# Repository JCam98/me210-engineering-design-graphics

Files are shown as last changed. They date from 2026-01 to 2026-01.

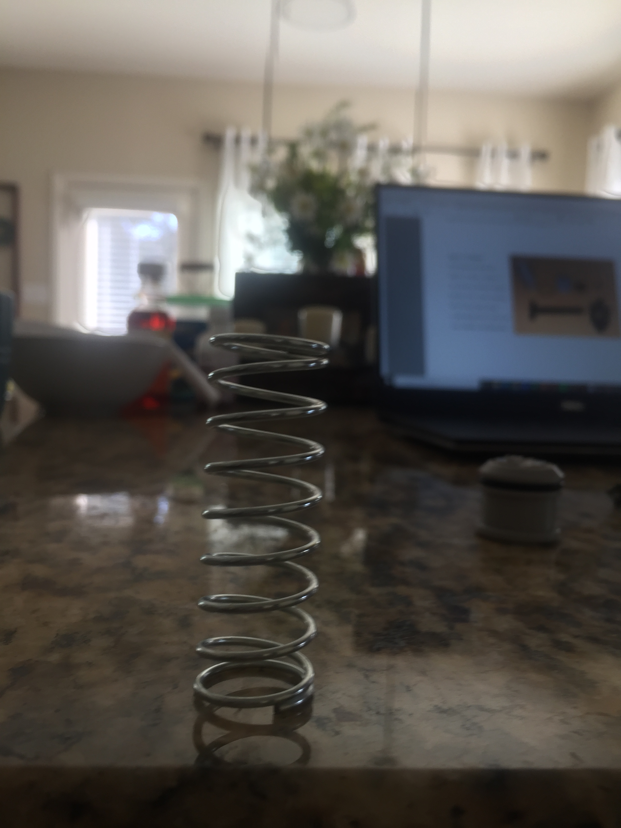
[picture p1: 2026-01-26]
Assignments/Reverse Engineering Project/Design Checks/Design_Check_2/Dissection_Notes/Plunger_Assembly_Spring/IMG-2650.JPG

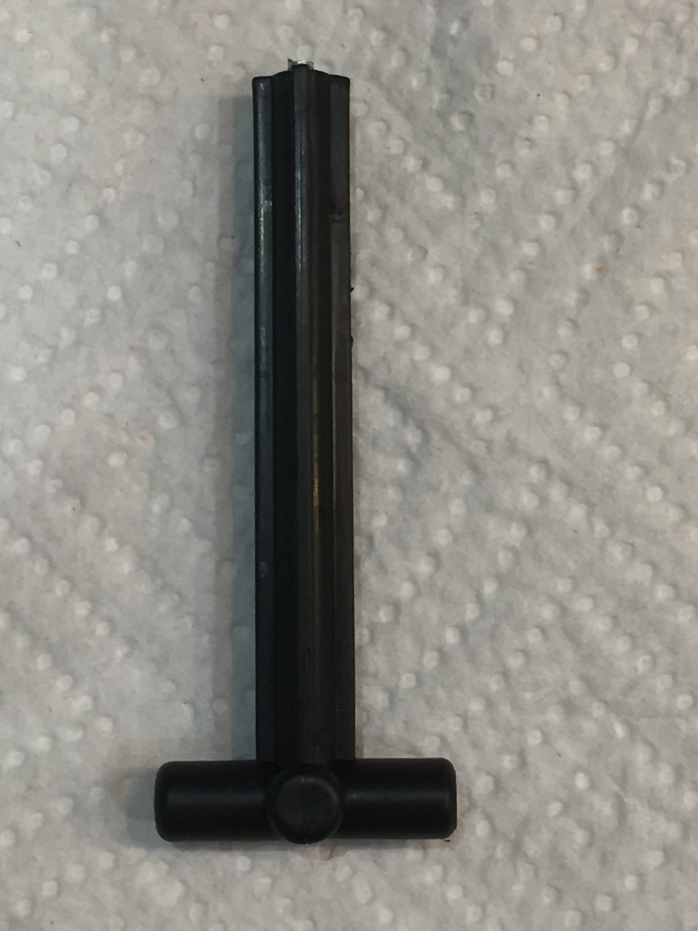
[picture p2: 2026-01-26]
Assignments/Reverse Engineering Project/Design Checks/Design_Check_2/Dissection_Notes/Plunger_Assembly_Shaft/IMG-2728.JPG

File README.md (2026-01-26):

# ME 210 - Engineering Design Graphics

## Description
This is an academic coursework repository containing a reverse engineering project for the course, ME 210: Engineering Design Graphics. This project documents a comprehensive reverse engineering analysis of a Nerf Rebelle toy blaster conducted as part of a mechanical engineering design course. The objective was to disassemble the product, understand its functional subsystems, and recreate the design through detailed engineering documentation and analysis. 

The work includes exploded assembly and sub-assembly sketches, mass properties evaluation, finite element analysis (FEA) of critical components under multiple load cases, and fully dimensioned orthographic drawings. Based on structural and performance insights gained from the analysis, a targeted redesign was proposed to improve component performance while maintaining functionality. Overall, the project demonstrates a structured approach to product teardown, mechanical analysis, and design improvement using industry-standard engineering methods and tools.

## Academic Use Notice
This repository contains completed coursework. Current students should not submit this work as their own.

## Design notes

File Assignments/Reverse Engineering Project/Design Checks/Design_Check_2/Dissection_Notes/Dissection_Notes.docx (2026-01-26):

Dissection Notes

1) To fully dissect the nerf gun, the plunger assembly (consisting of parts 1-8) was first removed from the plastic casing by unscrewing the four stainless steel screws connecting the baseplate to the plastic casing.
2) A flathead tool was then used to remove the rubber o-ring, rubber seal, and steel rivet on the top of the plastic shaft head of the plunger.
3) This, in turn, allowed for three remaining pieces of the plunger assembly, (plastic shaft head, plastic shaft, and plunger assembly spring) to be disassembled.
4) Next, a hacksaw was used to split the plastic casing of the gun into two equal parts, and allowed for the removal of the plastic trigger from the housing assembly.
5) The segment of the plastic casing with the barrel was then disassembled by removing the barrel spring by hand from its two fixed supports, which in turn, allowed for the barrel back panel to be removed. The last remaining part in the housing assembly, the bullet holder is fixed at one end, and free to rotate into and out of the barrel at the other.

Views of the plunger and housing assemblies along with their associated components in the order in which they are disassembled will be provided in detail below.

Full Dissection

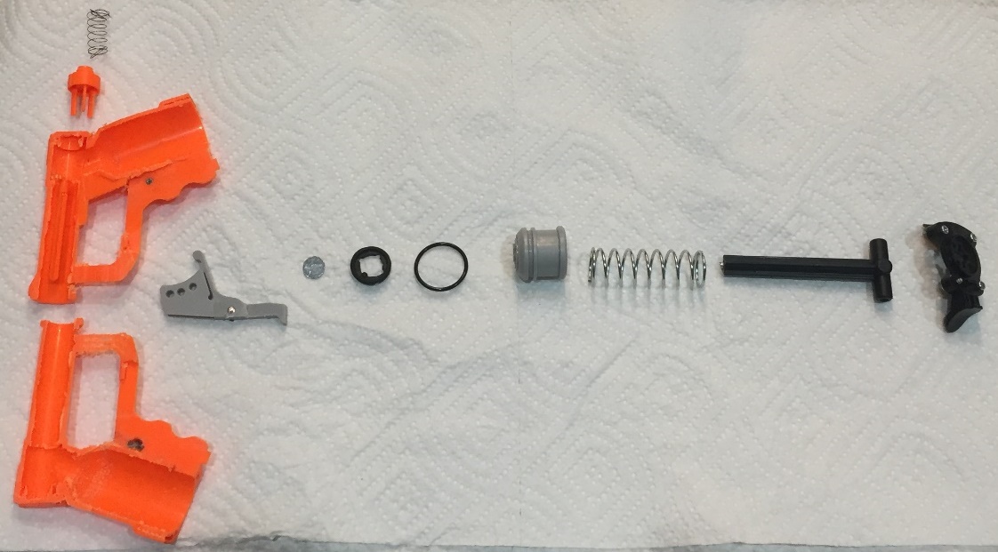
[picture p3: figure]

Figure 1: Full Dissection of the Nerf Gun

Plunger Assembly

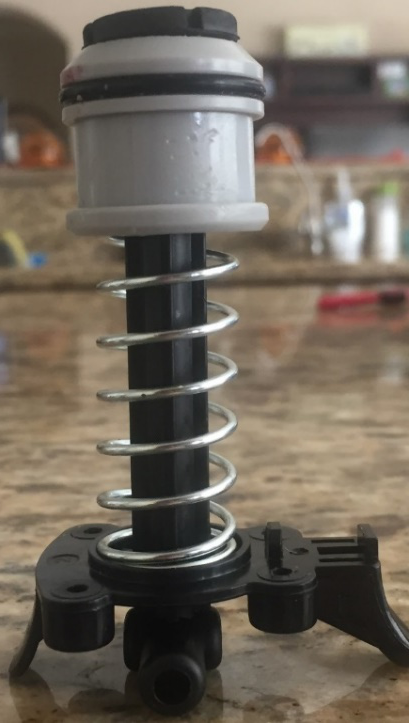
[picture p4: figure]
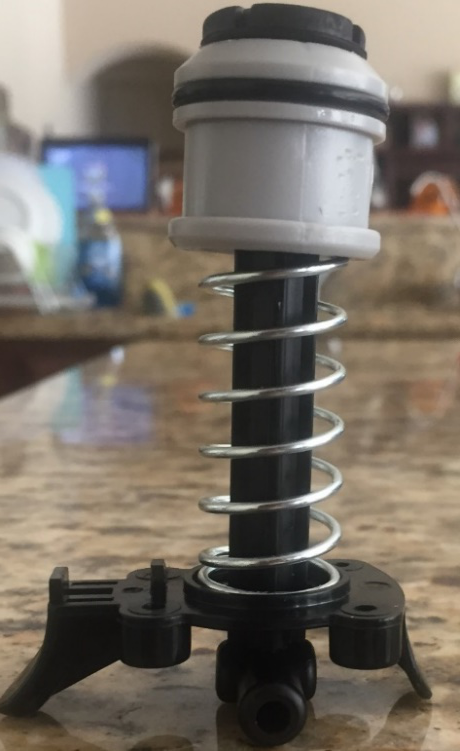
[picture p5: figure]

Figure 5: Plunger Assembly (Right View)

Figure 2: Plunger Assembly (Front View)

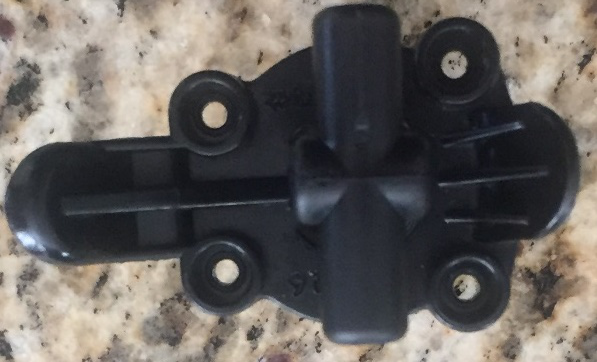
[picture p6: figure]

Figure 7: Plunger Assembly (Bottom View)

Figure 4: Plunger Assembly (Left View)

Figure 3: Plunger Assembly (Back View)

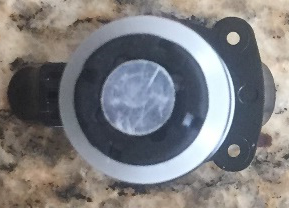
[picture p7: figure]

Figure 6: Plunger Assembly (Top View)

Plunger Dissassembly

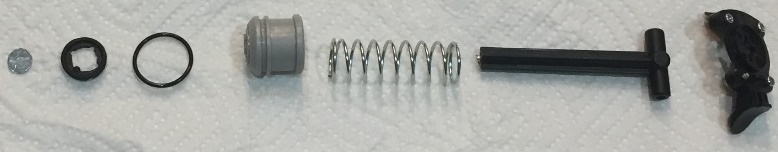
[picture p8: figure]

Figure 8: Disassembly of the Plunger

Baseplate

Figure 11: Plunger Assembly Baseplate (Left View)

Figure 9: Plunger Assembly Baseplate (Front View)

Figure 10: Plunger Assembly Baseplate (Back View)

Figure 12: Plunger Assembly Baseplate (Right View)

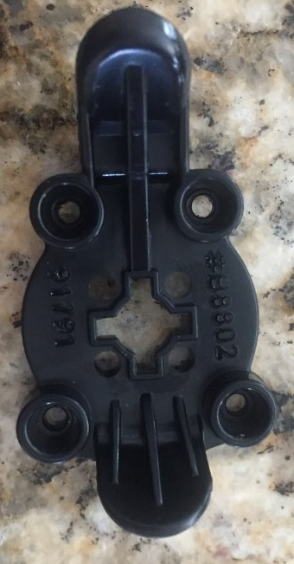
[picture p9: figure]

Figure 14: Plunger Assembly Baseplate (Bottom View)

Figure 13: Plunger Assembly Baseplate (Top View)

Phillips Screws

Figure 15: Phillips Screws

Plunger Assembly Shaft

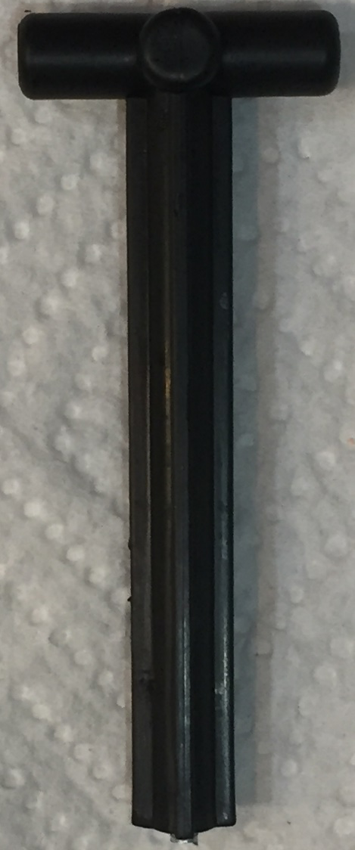
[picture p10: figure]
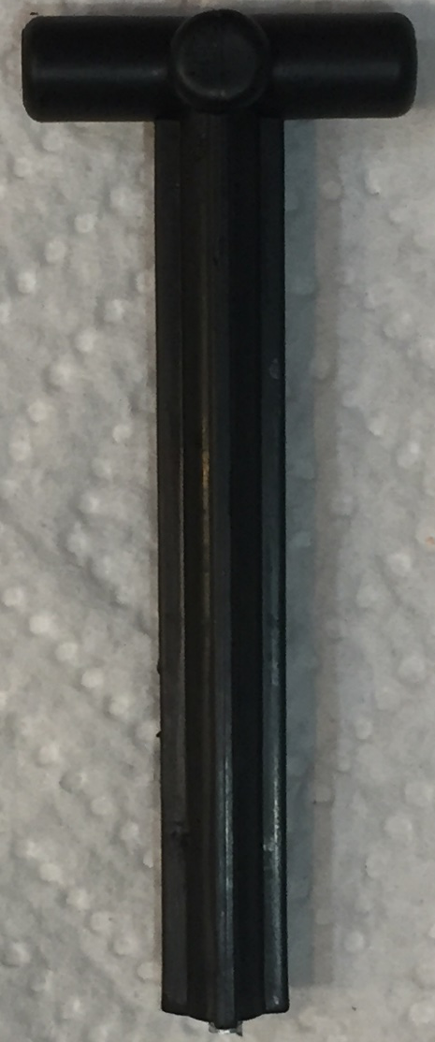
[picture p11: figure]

Figure 16: Plunger Assembly Shaft (Front View)

Figure 19: Plunger Assembly Shaft (Right View)

Figure 18: Plunger Assembly Shaft (Left View)

Figure 17: Plunger Assembly Shaft (Back View)

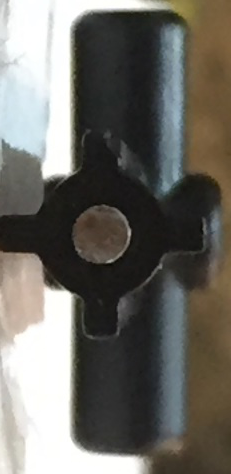
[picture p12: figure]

Figure 21: Plunger Assembly Shaft (Bottom View)

Figure 20: Plunger Assembly Shaft (Top View)

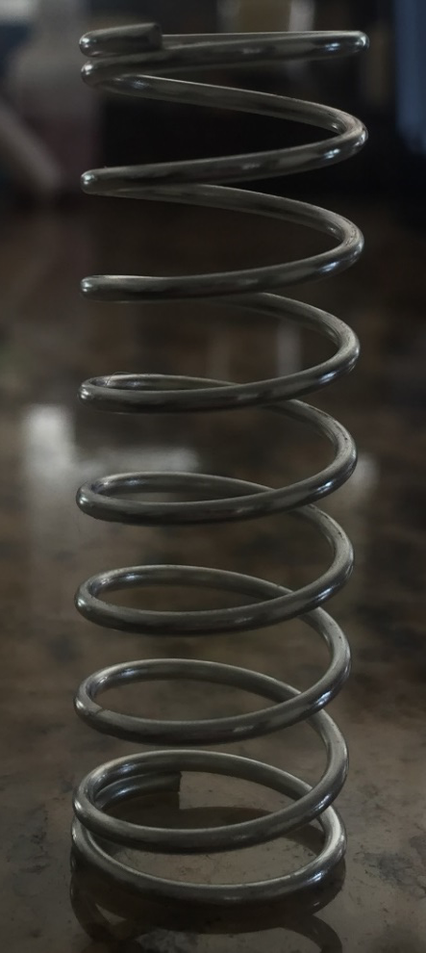
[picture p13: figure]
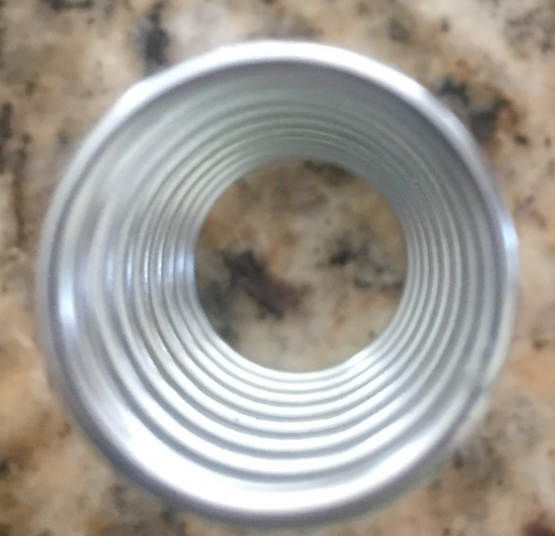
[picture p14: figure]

Plunger Assembly Spring

Figure 22: Plunger Assembly Spring (Side View)

Figure 22: Plunger Assembly Spring (Bottom View)

Figure 22: Plunger Assembly Spring (Top View)

Plunger Assembly Rubber O-Ring

Figure 24: Plunger Assembly Rubber O-Ring (Side View)

Figure 23: Plunger Assembly Rubber O-Ring (Top View)

Plunger Assembly Rubber Seal

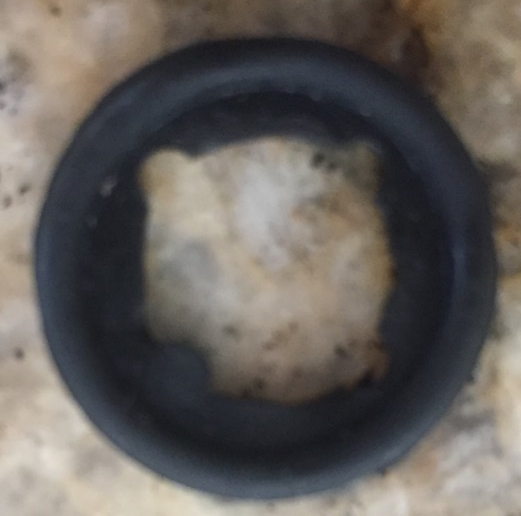
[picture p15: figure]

Figure 25: Plunger Assembly Rubber Seal (Top View)

Figure 25: Plunger Assembly Rubber Seal (Bottom View)

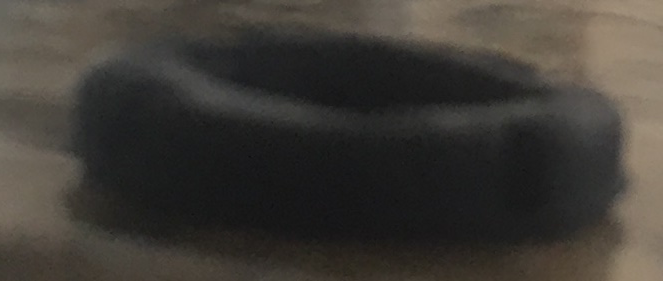
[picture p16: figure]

Figure 26: Plunger Assembly Rubber Seal (Side View)

Plastic Shaft Head

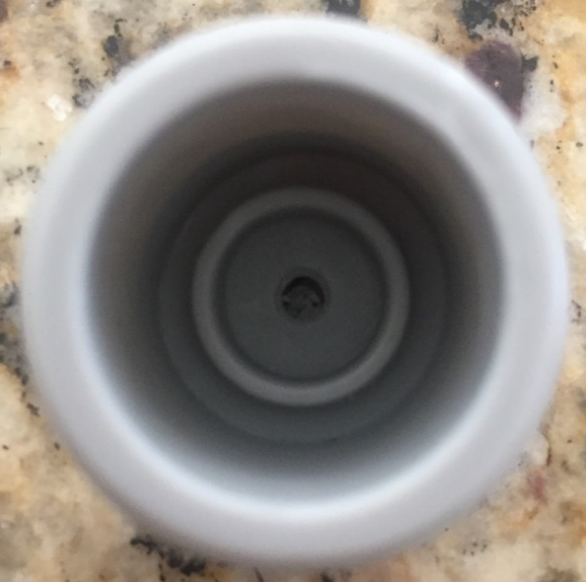
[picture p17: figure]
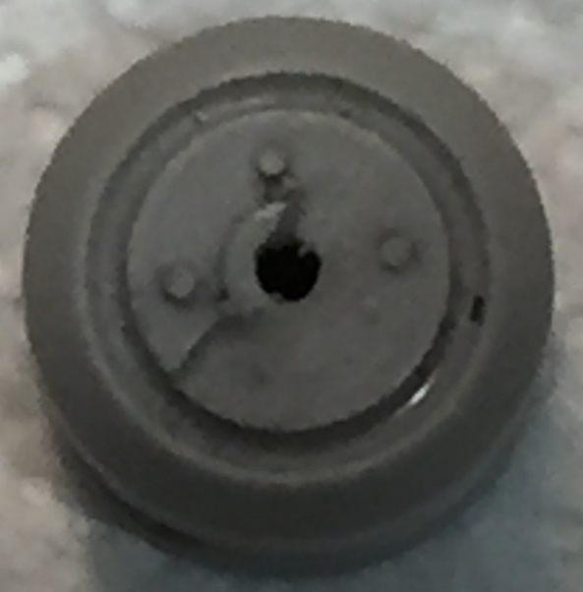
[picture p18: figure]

Figure 28: Plunger Assembly Rubber Seal (Bottom View)

Figure 27: Plunger Assembly Plastic Shaft Head (Top View)

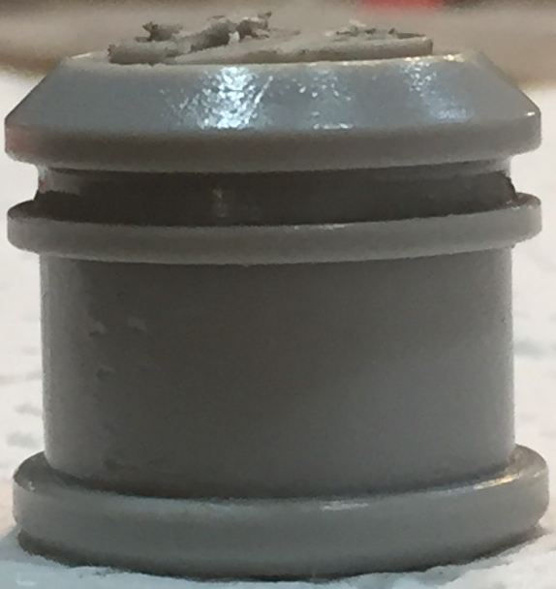
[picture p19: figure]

Figure 29: Plunger Assembly Rubber Seal (Side View)

Plunger Assembly Plastic Shaft Head Rivet

Figure 31: Plunger Assembly Plastic Shaft Head Rivet (Bottom View)

Figure 30: Plunger Assembly Plastic Shaft Head Rivet (Top View)

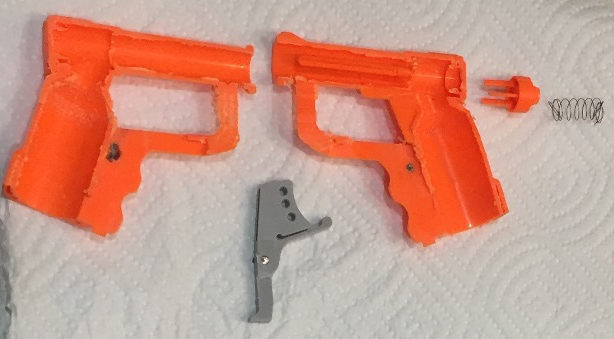
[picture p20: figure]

Housing Disassembly

Figure 32: Disassembly of Housing

Housing Assembly Trigger

Figure 33: Housing Assembly Trigger (Front View)

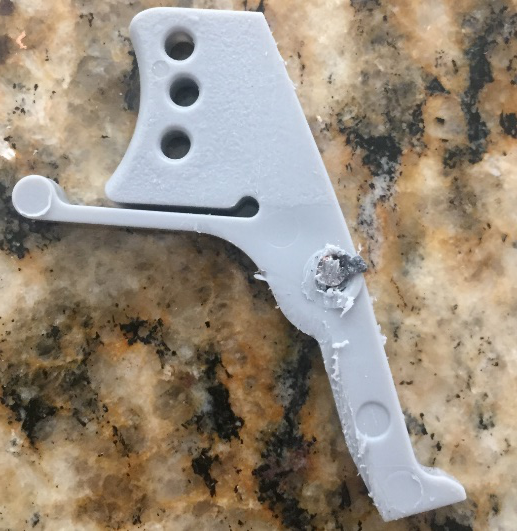
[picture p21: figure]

Figure 34: Housing Assembly Trigger (Back View)

Figure 35: Housing Assembly Trigger (Left View)

Figure 38: Housing Assembly Trigger (Bottom View)

Figure 37: Housing Assembly Trigger (Top View)

Figure 36: Housing Assembly Trigger (Right View)

Housing Assembly Trigger Rivet

Figure 39: Housing Assembly Trigger Rivet Void (As it appears on Plastic left view of plastic casing)

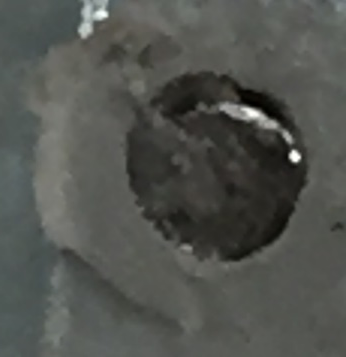
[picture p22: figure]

Figure 41: Housing Assembly Trigger Rivet (As it appears on left and right views of trigger)

Figure 40: Housing Assembly Trigger Rivet (As it appears on right view of plastic casing)

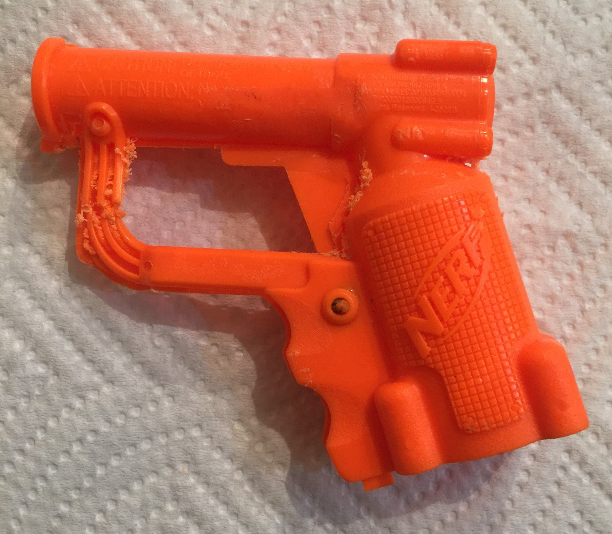
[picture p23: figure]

Housing Assembly Plastic Case

Figure 44: Housing Assembly Plastic Case (Left View)

Figure 42: Housing Assembly Plastic Case (Front View)

Figure 43: Housing Assembly Plastic Case (Back View)

Figure 45: Housing Assembly Plastic Case (Right View)

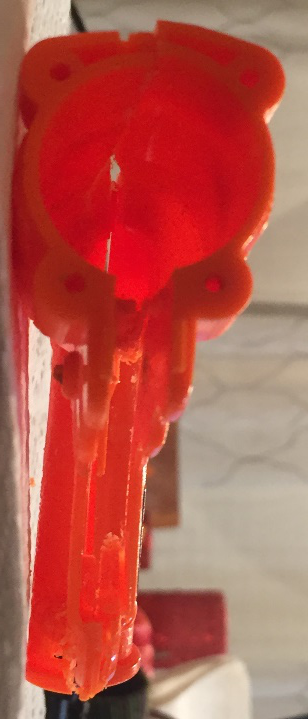
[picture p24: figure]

Figure 47: Housing Assembly Plastic Case (Bottom View)

Figure 46: Housing Assembly Plastic Case (Top View)

Figure 49: Housing Assembly Plastic Case (View of Inside of Right Segment)

Figure 48: Housing Assembly Plastic Case (View of Inside of Left Segment)

Housing Assembly Barrell Spring

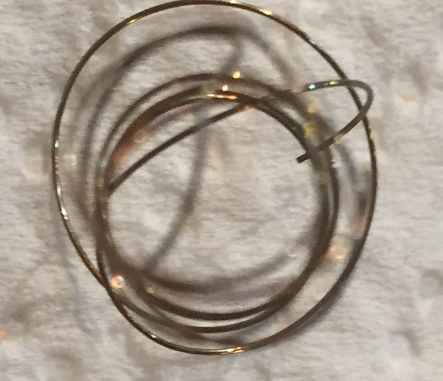
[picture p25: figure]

Figure 51: Housing Assembly Barrel Spring (Bottom View)

Figure 50: Housing Assembly Barrel Spring (Top View)

Figure 52: Housing Assembly Barrel Spring (Side View)

Housing Assembly Barrell Back Panel

Figure 54: Housing Assembly Barrel Back Panel (Back View)

Figure 53: Housing Assembly Barrel Back Panel (Front View)

Figure 55: Housing Assembly Barrel Back Panel (Side View)

Housing Assembly Bullet Holder

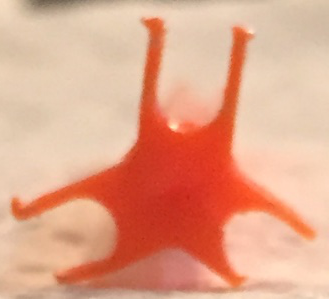
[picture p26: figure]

Figure 56: Housing Assembly Bullet Holder (Front View)

Figure 58: Housing Assembly Bullet Holder (Side View)

Figure 57: Housing Assembly Bullet Holder (Back View)

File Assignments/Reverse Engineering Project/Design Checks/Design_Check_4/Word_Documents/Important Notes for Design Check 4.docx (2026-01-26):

Important Notes for Design Check 4

- Rearrange the solidworks part drawings in the order of most to least importance (while still preserving the mini-assemblies) (i.e. springs, washers, etc. should be at the bottom of the report)
- Include Cover Page

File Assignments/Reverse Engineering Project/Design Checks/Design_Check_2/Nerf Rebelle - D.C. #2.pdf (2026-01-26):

# Design Graphics Team Project Fall 2020

# Reverse Engineering a Toy Nerf Gun

# Nerf Rebelle

## Audrey Pick - Team Leader

17295

### (audreygpick@gmail.com)

## Owen Mann

17350

### (owen.mann@utexas.edu)

## Keri Christian

17350

### (keri.em.christian@gmail.com)

## Justin Campbell

17350

### (campbelljustin989@gmail.com)

## Brenna Hurley

17295

### (hurleybren@gmail.com)

## Lab Instructor: Mark Chiarello

# Gantt Chart


Figure 2.2 A visualization of the intermediate and final due dates for the assignment.

## Each Intermediary design check is listed, along with when it will be assigned and when

it is due. The final due date of the cumulative report and presentation is also included.

# Black Box Diagram


Figure 2.3 The Black Box Diagram displays the function of the nerf gun. It has three parts: a. the inputs (pull on the plunger shaft, displacement on spring, and release with trigger) that go into the gun; b. the black box that shows the transformation (-(½)kx^2=(½)mv^2 or in other words, transform displacement to velocity) of inputs to

outputs; and c. the outputs (the bullet gains velocity, and the bullet shoots) that go out of the gun.

## Dissection Notes

1) To fully dissect the nerf gun, the plunger assembly (consisting of parts 1-8) was first

## removed from the plastic casing by unscrewing the four stainless steel screws

connecting the baseplate to the plastic casing.
2) A flathead tool was then used to remove the rubber o-ring, rubber seal, and steel rivet on the top of the plastic shaft head of the plunger.
3) This, in turn, allowed for three remaining pieces of the plunger assembly, (plastic shaft head, plastic shaft, and plunger assembly spring) to be disassembled.
4) Next, a hacksaw was used to split the plastic casing of the gun into two equal parts, and allowed for the removal of the plastic trigger from the housing assembly.

5) The segment of the plastic casing with the barrel was then disassembled by removing the barrel spring by hand from its two fixed supports, which in turn, allowed for the barrel back panel to be removed. The last remaining part in the housing assembly, the bullet holder is fixed at one end, and free to rotate into and out of the barrel at the

other.

## Views of the plunger and housing assemblies along with their associated components in the

order in which they are disassembled will be provided in detail below.

## Full Dissection


Figure 1: Full Dissection of the Nerf Gun

## Plunger Assembly


Figure 2: Plunger
Assembly (Front View)

Figure 3: Plunger
Assembly (Back View)
Figure 4: Plunger Assembly (Left View) | Figure 5: Plunger Assembly (Right View)
Figure 6: Plunger Assembly (Top View) | Figure 7: Plunger Assembly (Bottom View)

## Plunger Dissassembly


Figure 8: Disassembly of the Plunger

## Baseplate

Figure 9: Plunger Assembly Baseplate (Front View) Figure 10: Plunger Assembly Baseplate (Back View)


Figure 11: Plunger Assembly Baseplate (Left View)

Figure 12: Plunger Assembly Baseplate (Right View)


Figure 13: Plunger Assembly Baseplate (Top View)

Figure 14: Plunger
Assembly Baseplate
(Bottom View)

## Phillips Screws

Figure 15: Phillips Screws

## Plunger Assembly Shaft


Figure 16: Plunger
Assembly Shaft
(Front View)

Figure 17: Plunger
Assembly Shaft
(Back View)

Figure 18: Plunger Assembly Shaft (Left View)

Figure 19: Plunger Assembly Shaft (Right View)

Figure 20: Plunger
Assembly Shaft (Top
View)

Figure 21: Plunger
Assembly Shaft
(Bottom View)

## Plunger Assembly Spring


Figure 22: Plunger Assembly Spring (Top View) Figure 22: Plunger Assembly Spring (Bottom View)


Figure 22: Plunger Assembly Spring (Side View)

## Plunger Assembly Rubber O-Ring

Figure 23: Plunger Assembly Rubber O-Ring (Top View)

Figure 24: Plunger Assembly Rubber O-Ring (Side View)

## Plunger Assembly Rubber Seal

Figure 25: Plunger Assembly Rubber Seal (Top View)


Figure 25: Plunger Assembly Rubber Seal (Bottom View)


Figure 26: Plunger Assembly Rubber Seal (Side View)

## Plastic Shaft Head


Figure 27: Plunger Assembly Plastic Shaft Head (Top View)


Figure 28: Plunger Assembly Rubber Seal (Bottom View)


Figure 29: Plunger Assembly Rubber Seal (Side View)

## Plunger Assembly Plastic Shaft Head Rivet


Figure 30: Plunger Assembly Plastic Shaft Head Rivet (Top View)

Figure 31: Plunger Assembly Plastic Shaft Head Rivet (Bottom View)

## Housing Disassembly


Figure 32: Disassembly of Housing

## Housing Assembly Trigger

Figure 33: Housing
Assembly Trigger
(Front View)

Figure 34: Housing
Assembly Trigger
(Back View)


Figure 35: Housing Assembly Trigger (Left View)


Figure 36: Housing Assembly Trigger (Right View)

Figure 38: Housing
Assembly Trigger
(Bottom View)

## Housing Assembly Trigger Rivet

Figure 39: Housing Assembly Trigger Rivet Void (As it appears on Plastic left view of plastic casing)

Figure 40: Housing Assembly Trigger Rivet (As it appears on right view of plastic casing)

Figure 41: Housing Assembly Trigger Rivet (As it appears on left and right views of trigger)

## Housing Assembly Plastic Case


Figure 42: Housing
Assembly Plastic Case
(Front View)

Figure 43: Housing Assembly Plastic Case (Back View)

Figure 44: Housing Assembly Plastic Case (Left View)

Figure 45: Housing Assembly Plastic Case (Right View)

Figure 46: Housing
Assembly Plastic
Case (Top View)

Figure 47: Housing
Assembly Plastic Case
(Bottom View)

Figure

4

8

: Housing Assembly Plastic Case (View of Inside of Left Segment)

Figure

4

9

: Housing Assembly Plastic Case

(View
of Inside of Right Segment)

## Housing Assembly Barrell Spring


Figure 50: Housing Assembly Barrel Spring (Top View)

Figure 51: Housing Assembly Barrel Spring (Bottom View)

Figure 52: Housing
Assembly Barrel Spring
(Side View)

## Housing Assembly Barrell Back Panel

Figure 54: Housing Assembly Barrel Back Panel (Back View)

Figure 53: Housing Assembly Barrel Back Panel (Front View)

Figure 55: Housing Assembly Barrel Back Panel (Side View)

## Housing Assembly Bullet Holder


Figure 56: Housing Assembly Bullet Holder (Front View)

Figure 57: Housing
Assembly Bullet Holder
(Back View)

Figure 58: Housing Assembly Bullet Holder (Side View)

# Fishbone Diagram


Figure 2.5: Fishbone Diagram displaying how our dissected parts are interconnected. The Nerf Gun is presented with its four subsystems off the spine of the diagram along with detailed parts along each spine’s fins.

# Parts List

# Nerf Gun

Part No. | Part Name | No. Required | Material
1 | Plunger Assembly Baseplate | 1 | Plastic
2 | Phillips Screw | 4 | Steel
3 | Plunger Assembly Shaft | 1 | Plastic
4 | Plunger Assembly Spring | 1 | Plastic
5 | Plunger Assembly Rubber O-Ring | 1 | Rubber
6 | Plunger Assembly Rubber Seal | 1 | Rubber
7 | Plunger Assembly Plastic Shaft Head | 1 | Plastic
8 | Plunger Assembly Plastic Shaft Head Rivet | 1 | Steel
9 | Housing Assembly Trigger | 1 | Plastic
10 | Housing Assembly Trigger Rivet | 1 | Steel
11 | Housing Assembly Plastic Case | 1 | Plastic
12 | Housing Assembly Barrel Spring | 1 | Copper
13 | Housing Assembly Barrel Back Panel | 1 | Plastic

14 | Housing Assembly

# Bullet Holder

1 | Plastic

Figure 2.6 Parts List for the Nerf Gun, lists out every part in order of disassembly including how many of them are used and what material they are made of.

# Design Check #2


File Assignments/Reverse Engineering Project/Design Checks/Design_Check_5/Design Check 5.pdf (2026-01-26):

Design Graphics Team Project Fall 2020

## Reverse Engineering a Toy Nerf Gun

Nerf Rebelle

Audrey Pick - Team Leader
17295
(audreygpick@gmail.com)

Owen Mann
17350
(owen.mann@utexas.edu)

Keri Christian
17350
(keri.em.christian@gmail.com)

Justin Campbell
17350
(campbelljustin989@gmail.com)

Brenna Hurley
17295
(hurleybren@gmail.com)


Lab Instructor: Mark Chiarello

Discussion of Mass Properties Analysis Report

The plastic casing of the gun was selected as the part for the generation of a

mass properties analysis report because, by enclosing all of the sub-assemblies in the

device, it is what the child makes physical contact with more so than any other part

during its use. The plastic casing will be manufactured out of an ABS plastic material

because it facilitates high strain resistance and yield strength that will make the gun

durable, and well-suited for exposure to mechanical wear and tear from child play.

Additionally, the material is a good thermal insulator, and therefore, the performance of

the gun will behave under a variety of outdoor environments.

The first of three mass properties that will be discussed in this report is the mass

of the plastic casing. According to Newton’s Second Law, mass is an intrinsic property

that measures the ability of an object to resist changes in motion under applied loads. In

this context, then, it can be realized that it is important to optimize the mass of the

plastic casing to ensure that the user will be able to comfortably maneuver the gun

during its occupation. The second mass property that will be discussed is the volume. It

is important to take this property into account in the design to ensure that the exterior

boundary surfaces of the gun are streamlined in size for the user. Lastly, the second

moment of inertia of the plastic casing about the x-axis (identified in the figure below)

will be examined to gain a solid understanding of the object’s tendencies to resist

rotation about the axis of the barrel, thus influencing the trajectory of the bullet.

Analysis of Mass Properties Here

Mass is important both from the standpoint of Newton’s Second Law and

manufacturing. The mass should be sufficient enough to resist acceleration from the

bullet firing and to maintain a good change of momentum for the bullet's initial velocity.

The mass of the case is 0.5 lbs, which is a good size as it can easily be held by a child

(Figure 5.2).

In addition, the volume, or the space that a shape occupies, is an important

consideration in the manufacturing of the toy gun. In our case, the volume of the toy is

1.34 cubic inches which is ideal for the standard user (Figure 5.2). The volume of the

gun greatly affects the holding and maneuvering of the toy, and this user experience is

of utmost importance. The volume is especially important for the vacuum seal created in

the handle portion of the gun, as it affects the displacement of the springs which

determine the kinetic energy given to the bullet when it fires. Moreover, the volume is an

important consideration when determining the various subsystems that are to be

enclosed in the case, and an appropriate volume perfectly encloses each part without

compromising their performance!

Lastly, from the derivation from Newton’s second law, torque = mass moment of

inertia multiplied by the angular acceleration. Therefore, the mass moment of inertia is

important to understand any possible rotation and how the case will resist it, as we want

the gun to fire straight. The mass moment of inertia taken about the x axis from the

mass properties is 0.22 lb-in²

(Figure 5.2) This is ideal as a larger mass moment of

inertia entails less rotation, so the design of the case overall will minimally rotate along

the axis most affected by the firing of the gun (Figure 5.1).


Figure 5.1 Plastic case with the center of mass, origin, and the axes of inertia.

Mass Properties Report


Figure 5.2 The Mass Analysis with the Mass Properties Discussed Highlighted

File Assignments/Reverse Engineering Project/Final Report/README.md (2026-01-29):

# Reverse Engineering Project

## Problem Statement

Plastic consumer products experience repeated mechanical loading that can lead to deformation or failure if not properly designed. Evaluating how internal components distribute stress and respond to applied loads is essential for improving durability, safety, and performance. This project addresses the need to assess the structural behavior of a commercial toy blaster through reverse engineering and analysis.

## Project Description & Purpose

This project reverse engineered a Nerf Rebelle toy blaster to examine its internal structure, component geometry, and load-bearing behavior. The goal was to document the design, evaluate structural performance under representative loading conditions, and identify opportunities for design improvement based on analytical results.

## Solution Approach

The blaster was disassembled and documented using exploded assembly sketches, mass property analysis, and detailed orthographic drawings. Finite element analysis (FEA) was conducted on key components to evaluate displacement, strain, and stress under applied loads of 75 N, 200 N, and 300 N. Simulation results informed a redesigned component geometry aimed at improving structural performance.

## Key Findings & Takeaways

FEA results identified stress concentrations and deformation patterns that increased with applied load, revealing design limitations in the original geometry. The redesigned component reduced stress concentrations through modified dimensions and improved load distribution. Overall, the project demonstrates how reverse engineering combined with FEA can guide effective, data-driven product design improvements.

## Tech Stack

This project involved the use of Solidworks as the Computer-Aided Design tool.



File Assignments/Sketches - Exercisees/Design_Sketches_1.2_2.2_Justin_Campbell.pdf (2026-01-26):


Bookend Support Isometric Drawing


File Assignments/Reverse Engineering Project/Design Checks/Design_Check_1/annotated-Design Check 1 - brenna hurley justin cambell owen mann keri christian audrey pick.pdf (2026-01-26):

### Design Graphics Team Project Fall 2020

## Reverse Engineering a Toy Nerf Gun

### Nerf Rebelle

Audrey Pick - Team Leader
17295
(audreygpick@gmail.com)

Owen Mann
17350
(owen.mann@utexas.edu)

Keri Christian
17350
(keri.em.christian@gmail.com)

Justin Campbell
17350
(campbelljustin989@gmail.com)

Brenna Hurley
17295
(hurleybren@gmail.com)


Lab Instructor: Mark Chiarello

### Project Proposal

For our project we will be reverse engineering a toy Nerf gun (See Figure 1). The specific Nerf

gun we will be taking apart to redesign is called the “Nerf N-Strike Elite Jolt Blaster”. It is a

smaller nerf gun that can only shoot 1 bullet at a time and the gun needs to be primed by pulling

down on the attachment before pulling the trigger to fire the gun.

Customer Perspective

A customer looking for a toy Nerf gun would mainly be looking at the object from the perspective

of how they can play with it. The main customer demographic would be small children, and they

will care about the overall look of the gun and will want it to look cool. The customer will be

concerned with how far the gun shoots the bullets. They will want to know how the gun actually

works including how many bullets it holds and if it uses a specific type of bullet or shooting

mechanism to know how to use the gun when playing (disc or bullet, barrel or no barrel). They

will care whether the toy gun’s bullets would hurt someone would be a factor in considering

buying this toy.

Engineers perspective

Engineers will be concerned about the material makeup of the toy nerf gun in order to make it

lightweight and also accomplish its function of shooting nerf bullets. It should also be a durable

material as it is intended to be played with. As the nerf gun is intended to be used by children, it

is important for the engineer to consider safety when designing the mechanism used for

shooting. The speed of the bullet and shape of the bullet should not lead to physical harm.

An engineer should consider the size of the nerf gun as it should be portable but also big

enough to contain the components needed to launch the bullets. It should also be balanced as to ensure a comfortable grip by the customer. The engineer should be aware of what kind of

shooting mechanism they want to employ to optimize the parameters for their specific kind of

shooting mechanism. This will determine how the gun shoots, how many bullets it can take, and

the way it will convert potential energy into kinetic energy.

Engineering Specifications List

- Testing for optimal shooting velocity and distance the bullet can travel (3-10 meters and

15-25 meters/second)

- Durability of nerf gun (meant to last a long time, about 1 to 5 years)
- Dimensions and of overall gun (2 x 12 x 12 cm - 3 x 13 x 13 cm)
- Low force of the bullet for safety (0.5-2 Newtons)
- Total weight of the gun (80-90 g)

Graphical Picture


Figure 1 The Nerf N-Strike Elite Jolt Blaster placed next to the foam nerf bullets. This gun can be purchased at https://www.amazon.com/Nerf-N-Strike-Elite-Jolt-Blaster/dp/B01HEQHXE8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 (https://www.amazon.com/Nerf-N-Strike-Elite-Jolt-Blaster/dp/B01HEQHXE8) in order to reverse engineer it. It is a smaller nerf gun that is reloaded manually and looks to use a hand pump spring mechanism for firing bullets.

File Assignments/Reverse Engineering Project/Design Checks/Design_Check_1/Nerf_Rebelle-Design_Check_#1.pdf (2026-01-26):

### Design Graphics Team Project Fall 2020

## Reverse Engineering a Toy Nerf Gun

### Nerf Rebelle

Audrey Pick - Team Leader
17295
(audreygpick@gmail.com)

Owen Mann
17350
(owen.mann@utexas.edu)

Keri Christian
17350
(keri.em.christian@gmail.com)

Justin Campbell
17350
(campbelljustin989@gmail.com)

Brenna Hurley
17295
(hurleybren@gmail.com)


Lab Instructor: Mark Chiarello

### Project Proposal

For our project we will be reverse engineering a toy Nerf gun (See Figure 1). The specific Nerf

gun we will be taking apart to redesign is called the “Nerf N-Strike Elite Jolt Blaster”. It is a

smaller nerf gun that can only shoot 1 bullet at a time and the gun needs to be primed by pulling

down on the attachment before pulling the trigger to fire the gun.

Customer Perspective

A customer looking for a toy Nerf gun would mainly be looking at the object from the perspective

of how they can play with it. The main customer demographic would be small children, and they

will care about the overall look of the gun and will want it to look cool. The customer will be

concerned with how far the gun shoots the bullets. They will want to know how the gun actually

works including how many bullets it holds and if it uses a specific type of bullet or shooting

mechanism to know how to use the gun when playing (disc or bullet, barrel or no barrel). They

will care whether the toy gun’s bullets would hurt someone would be a factor in considering

buying this toy.

Engineers perspective

Engineers will be concerned about the material makeup of the toy nerf gun in order to make it

lightweight and also accomplish its function of shooting nerf bullets. It should also be a durable

material as it is intended to be played with. As the nerf gun is intended to be used by children, it

is important for the engineer to consider safety when designing the mechanism used for

shooting. The speed of the bullet and shape of the bullet should not lead to physical harm.

An engineer should consider the size of the nerf gun as it should be portable but also big

enough to contain the components needed to launch the bullets. It should also be balanced as to ensure a comfortable grip by the customer. The engineer should be aware of what kind of

shooting mechanism they want to employ to optimize the parameters for their specific kind of

shooting mechanism. This will determine how the gun shoots, how many bullets it can take, and

the way it will convert potential energy into kinetic energy.

Engineering Specifications List

- Testing for optimal shooting velocity and distance the bullet can travel (3-10 meters and

15-25 meters/second)

- Durability of nerf gun (meant to last a long time, about 1 to 5 years)
- Dimensions and of overall gun (2 x 12 x 12 cm - 3 x 13 x 13 cm)
- Low force of the bullet for safety (0.5-2 Newtons)
- Total weight of the gun (80-90 g)

Graphical Picture


Figure 1 The Nerf N-Strike Elite Jolt Blaster placed next to the foam nerf bullets. This gun can be purchased at https://www.amazon.com/Nerf-N-Strike-Elite-Jolt-Blaster/dp/B01HEQHXE8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 (https://www.amazon.com/Nerf-N-Strike-Elite-Jolt-Blaster/dp/B01HEQHXE8) in order to reverse engineer it. It is a smaller nerf gun that is reloaded manually and looks to use a hand pump spring mechanism for firing bullets.

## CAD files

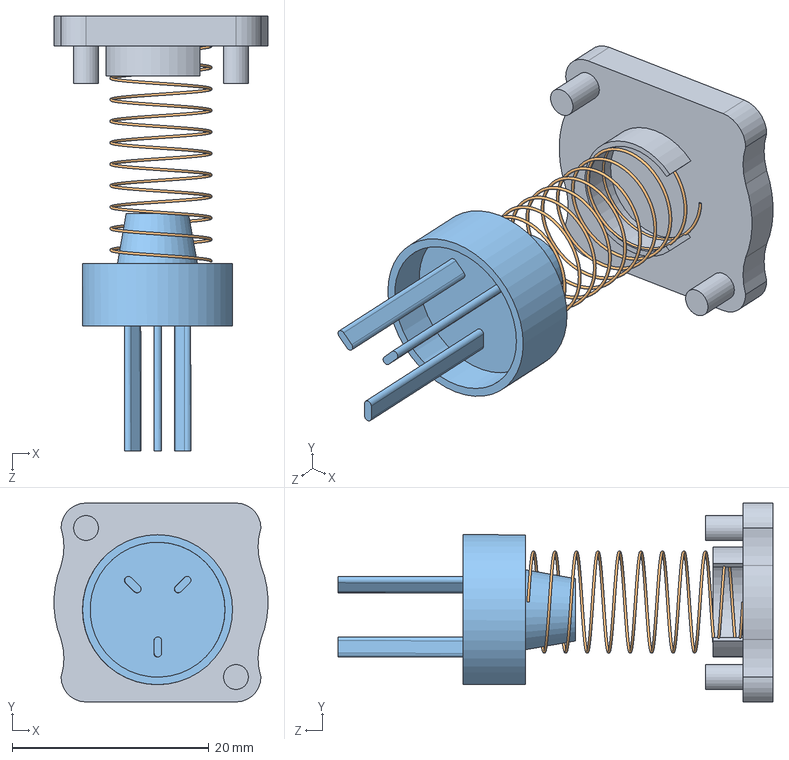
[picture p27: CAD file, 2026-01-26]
Assignments/Reverse Engineering Project/Design Checks/Design_Check_4/Assembly_Files/Firing_Barrel_Assembly.SLDASM
21.7 x 20.2 x 44.2 mm
Part 12 - Barrel Back Plate
Part 13 - Barrel Spring
Part 14 - Bullet Holder

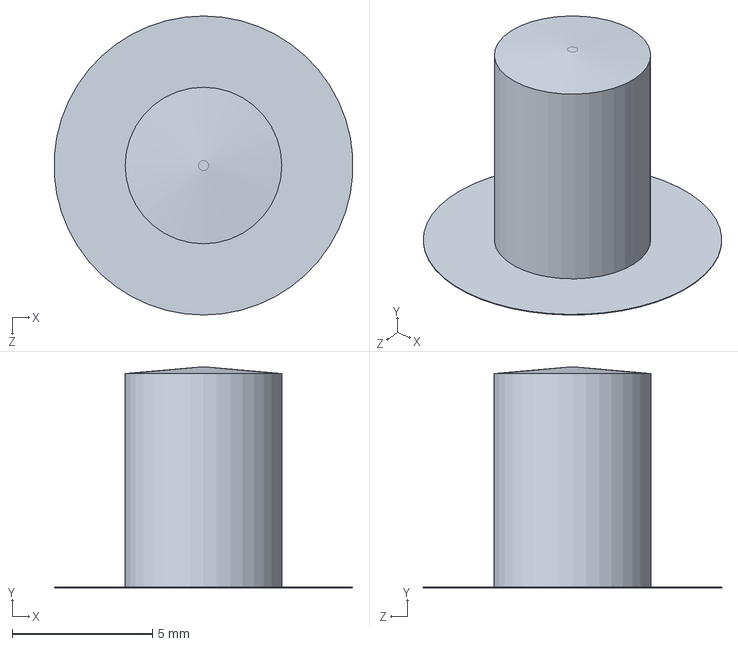
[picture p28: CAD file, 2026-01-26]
Assignments/Reverse Engineering Project/Design Checks/Design_Check_4/Part_Files /Plunger_Assembly_Shaft_Head_Rivet.SLDPRT
10.6 x 7.87 x 10.7 mm

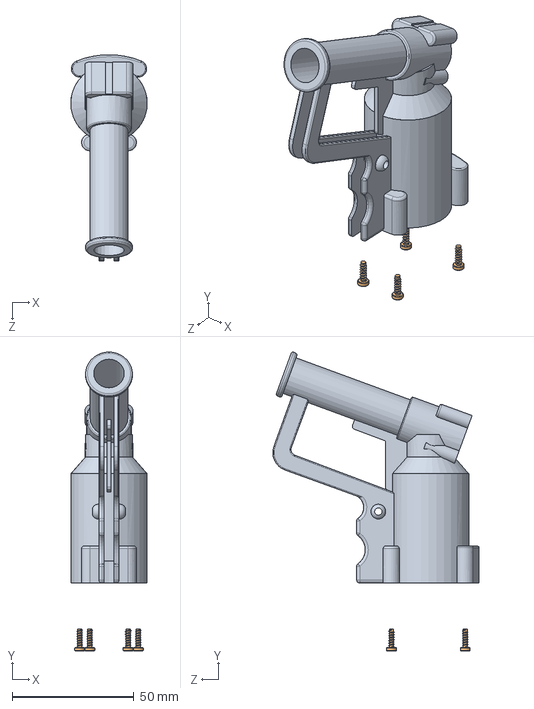
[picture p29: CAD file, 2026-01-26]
Assignments/Reverse Engineering Project/Design Checks/Design_Check_4/Assembly_Files/Housing-Assembly.SLDASM
31.5 x 123.0 x 85.0 mm
PLASTIC CASE fixed barrel
phillips screw x 4

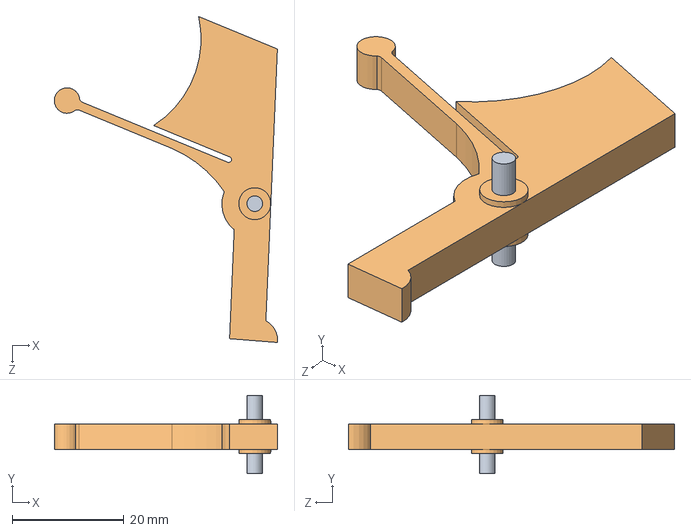
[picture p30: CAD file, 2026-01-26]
Assignments/Reverse Engineering Project/Design Checks/Design_Check_4/Assembly_Files/trigger_assembly.SLDASM
39.9 x 14.0 x 58.3 mm
10 trigger rivet
11 trigger

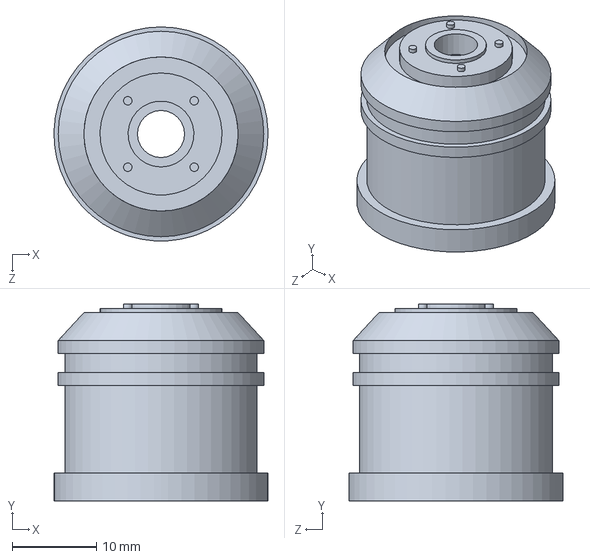
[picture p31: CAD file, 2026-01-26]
Assignments/Reverse Engineering Project/Design Checks/Design_Check_4/Part_Files /Plunger_Assembly_Shaft_Head.SLDPRT
25.4 x 23.4 x 25.4 mm

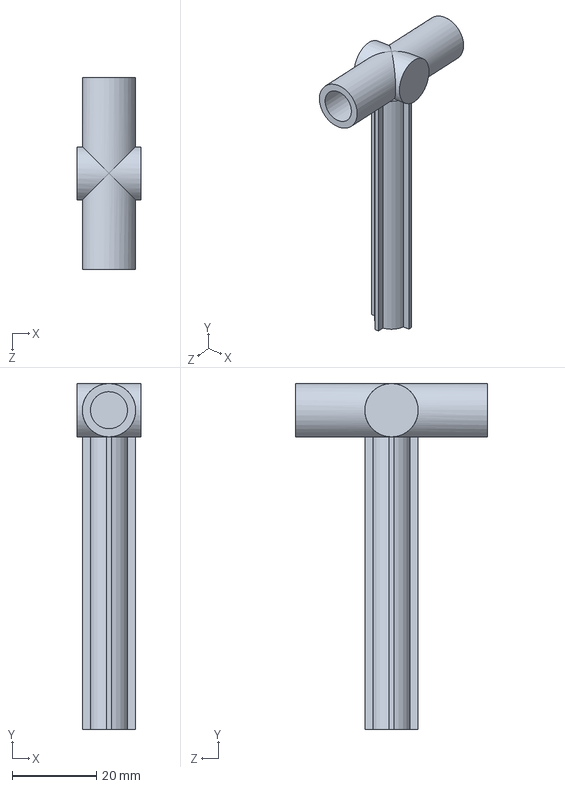
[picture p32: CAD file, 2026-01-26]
Assignments/Reverse Engineering Project/Design Checks/Design_Check_4/Part_Files /Plunger_Assembly_Shaft.SLDPRT
15.2 x 82.3 x 45.7 mm

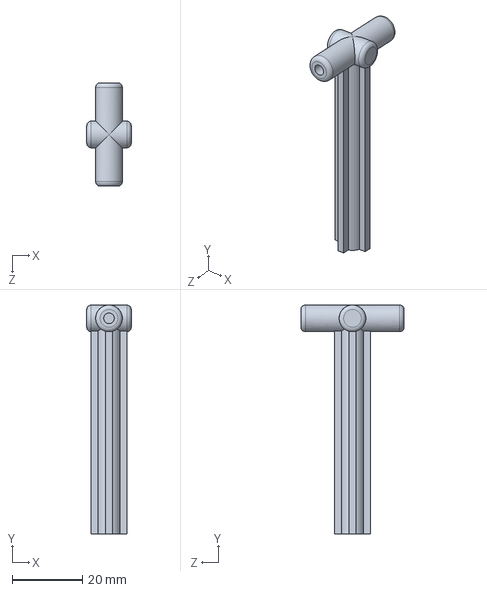
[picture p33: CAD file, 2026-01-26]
Assignments/Reverse Engineering Project/Design Checks/Design_Check_6/SHAFT_FEA_ATTEMPT.SLDPRT
12.7 x 65.3 x 29.5 mm

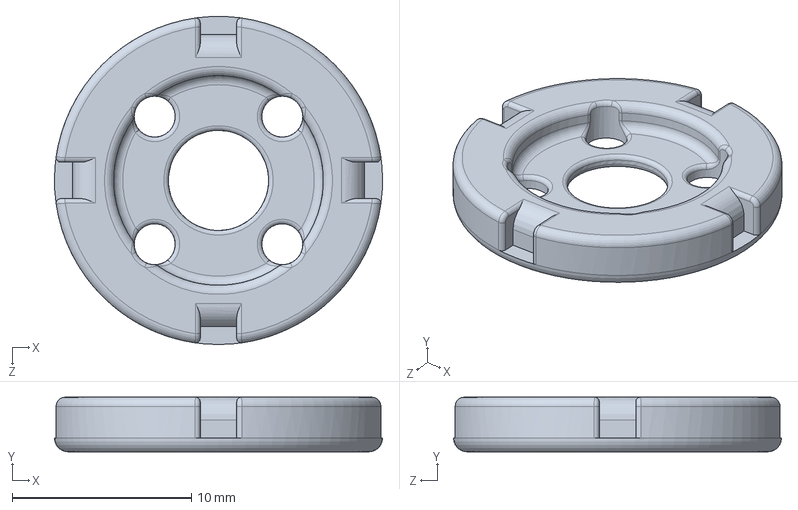
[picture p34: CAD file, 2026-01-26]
Assignments/Reverse Engineering Project/Design Checks/Design_Check_4/Part_Files /RUBBER_SEAL.SLDPRT
18.3 x 3.05 x 18.3 mm

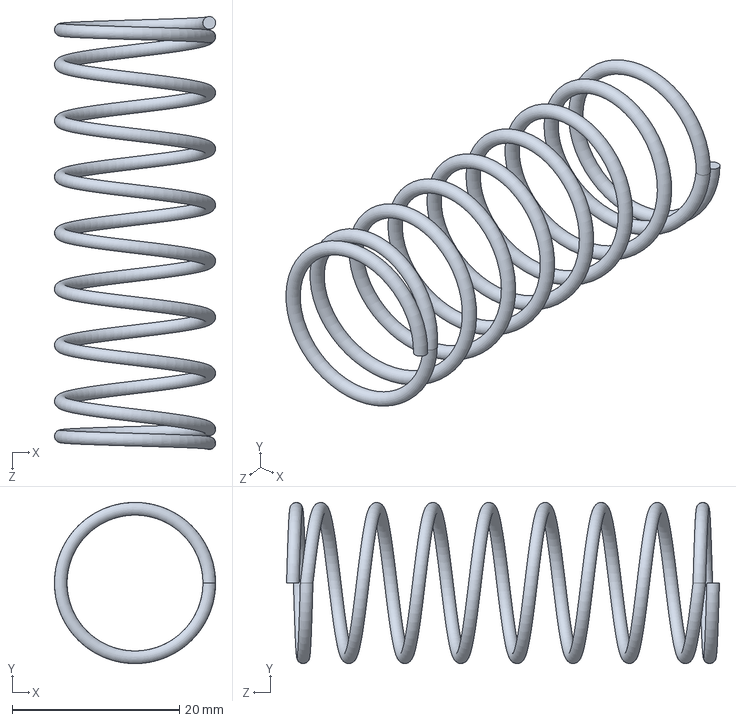
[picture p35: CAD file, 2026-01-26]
Assignments/Reverse Engineering Project/Design Checks/Design_Check_4/Part_Files /VACUUM_SPRING.SLDPRT
19.3 x 19.3 x 51.8 mm

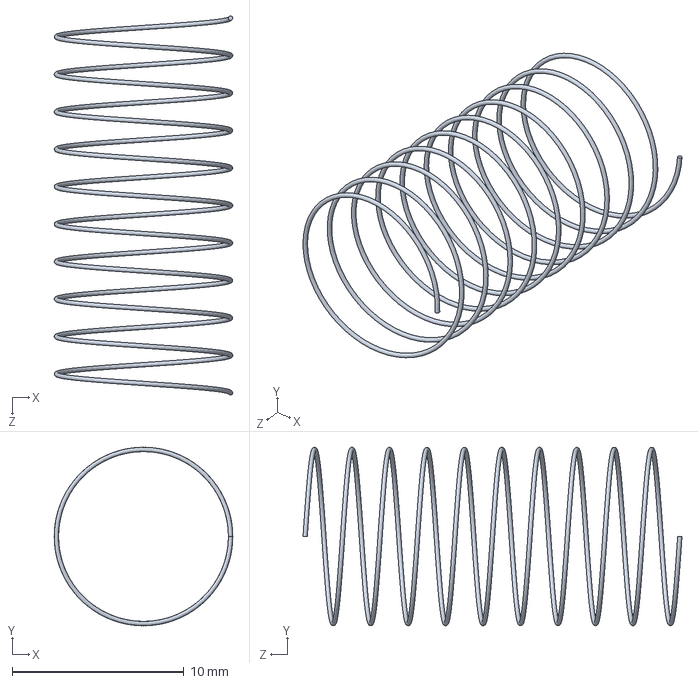
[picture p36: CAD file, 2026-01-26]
Assignments/Reverse Engineering Project/Design Checks/Design_Check_4/Part_Files /Part_13_-_Barrel_Spring.SLDPRT
10.4 x 10.4 x 22.1 mm

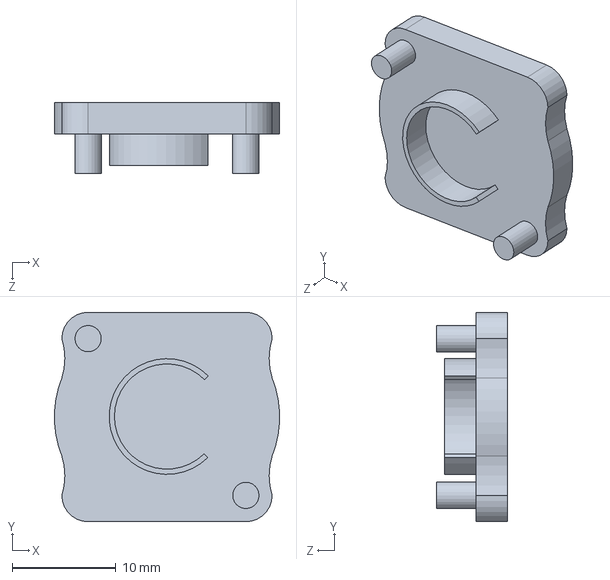
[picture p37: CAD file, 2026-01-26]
Assignments/Reverse Engineering Project/Design Checks/Design_Check_4/Part_Files /Part_12_-_Barrel_Back_Plate.SLDPRT
21.7 x 20.2 x 6.86 mm

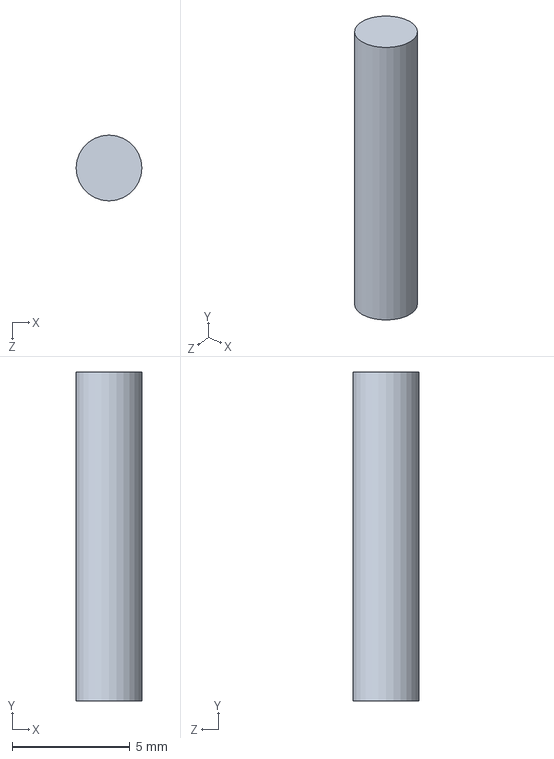
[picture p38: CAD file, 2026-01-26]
Assignments/Reverse Engineering Project/Design Checks/Design_Check_4/Part_Files /10__trigger_rivet.SLDPRT
2.79 x 14.0 x 2.79 mm

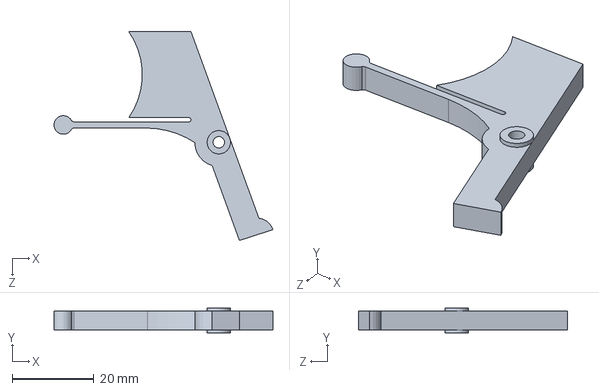
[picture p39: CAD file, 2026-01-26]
Assignments/Reverse Engineering Project/Design Checks/Design_Check_4/Part_Files /11_trigger.SLDPRT
53.6 x 6.10 x 51.1 mm

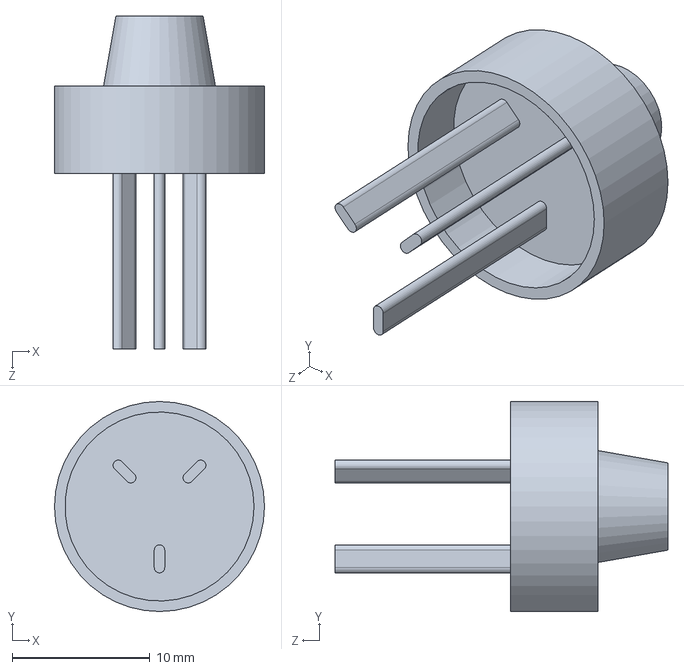
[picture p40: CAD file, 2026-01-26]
Assignments/Reverse Engineering Project/Design Checks/Design_Check_4/Part_Files /Part_14_-_Bullet_Holder.SLDPRT
15.2 x 15.2 x 24.1 mm

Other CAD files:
Assignments/Reverse Engineering Project/Design Checks/Design_Check_4/Part_Files /PLASTIC_CASE_fixed_barrel.SLDPRT
Assignments/Reverse Engineering Project/Design Checks/Design_Check_4/Part_Files /BASE_PLATE.SLDPRT
Assignments/Reverse Engineering Project/Design Checks/Design_Check_4/Part_Files /7_rubber_o-ring.SLDPRT
Assignments/Reverse Engineering Project/Design Checks/Design_Check_4/Part_Files /5_vacuum_spring.SLDPRT
Assignments/Reverse Engineering Project/Design Checks/Design_Check_4/Drawing_files/PART_3_PHILLIPS_SCREW.SLDDRW
Assignments/Reverse Engineering Project/Design Checks/Design_Check_4/Drawing_files/Plunger_Assembly_Shaft.SLDDRW
Assignments/Reverse Engineering Project/Design Checks/Design_Check_4/Drawing_files/Plunger_Assembly_Shaft_Head.SLDDRW
Assignments/Reverse Engineering Project/Design Checks/Design_Check_4/Drawing_files/Shaft_Head_Rivet.SLDDRW
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

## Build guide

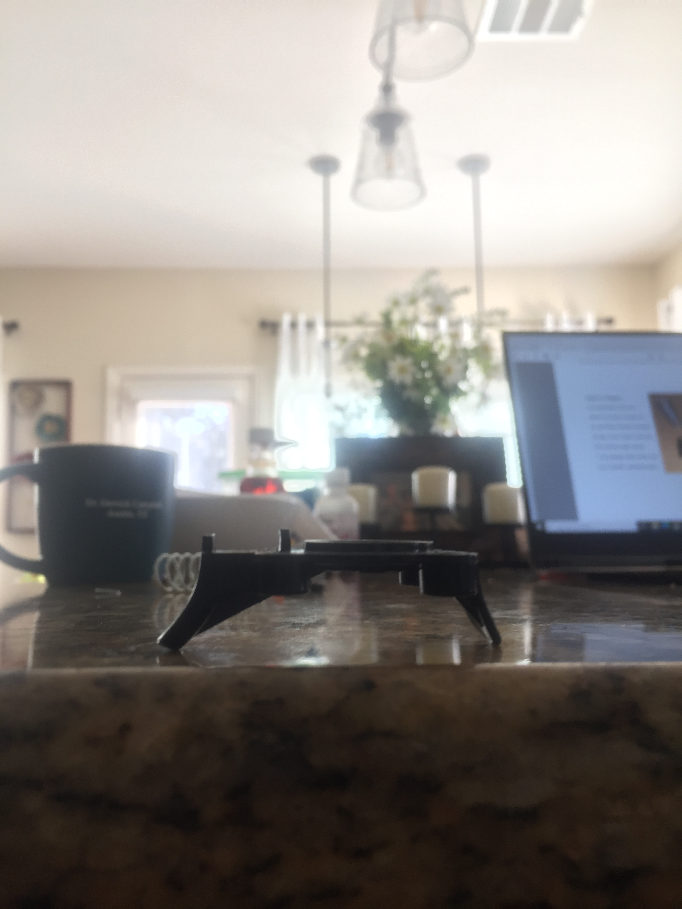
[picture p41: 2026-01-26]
Assignments/Reverse Engineering Project/Design Checks/Design_Check_2/Dissection_Notes/Plunger_Assembly_Baseplate/IMG-2669.JPG

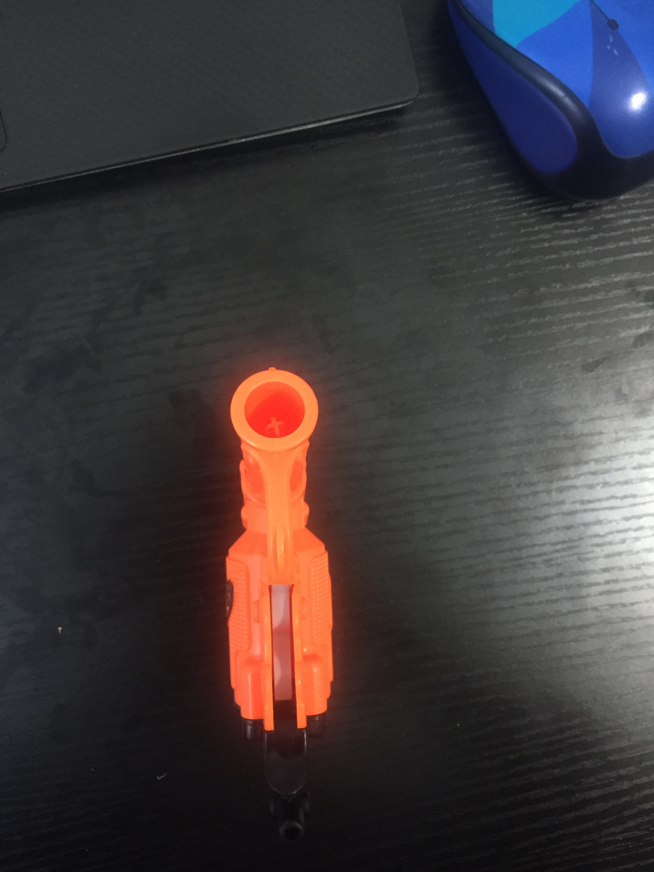
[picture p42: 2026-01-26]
Assignments/Reverse Engineering Project/Design Checks/Design_Check_2/Dissection_Notes/Housing_Assembly/IMG-2634.JPG

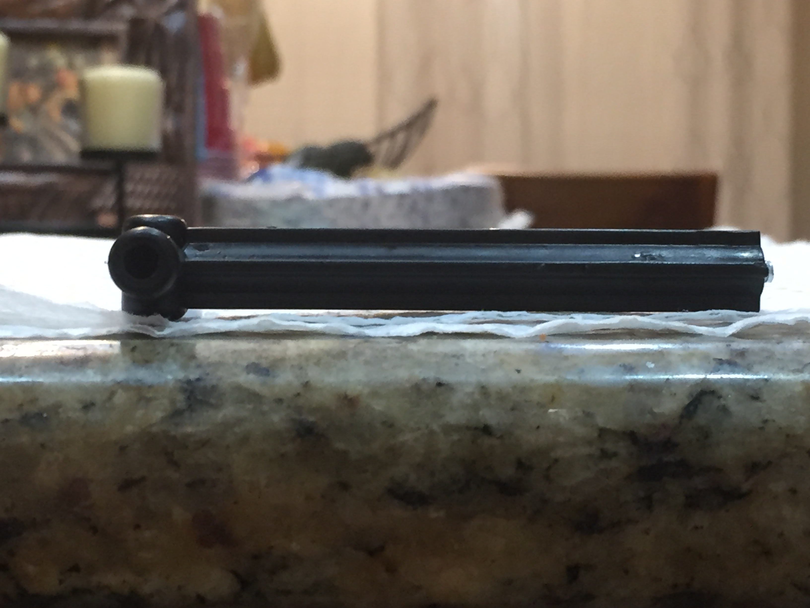
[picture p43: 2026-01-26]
Assignments/Reverse Engineering Project/Design Checks/Design_Check_2/Dissection_Notes/Plunger_Assembly_Shaft/IMG-2730.JPG

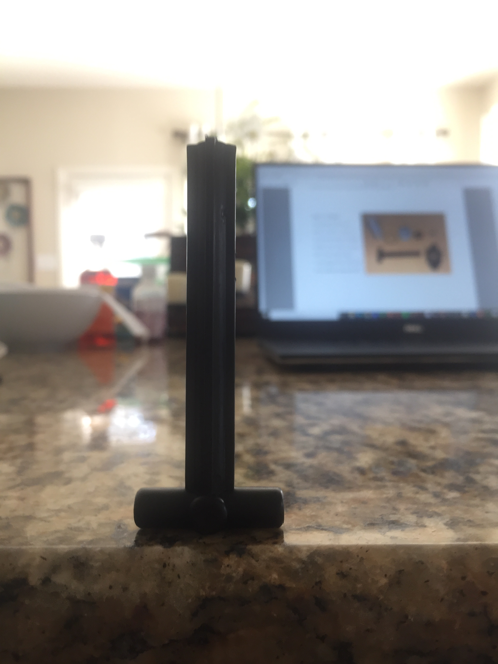
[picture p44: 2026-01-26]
Assignments/Reverse Engineering Project/Design Checks/Design_Check_2/Dissection_Notes/Plunger_Assembly_Shaft/IMG-2661.JPG
